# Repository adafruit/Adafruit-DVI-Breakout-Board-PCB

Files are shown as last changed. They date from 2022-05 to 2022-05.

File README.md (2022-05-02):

## Adafruit DVI Breakout Board - For HDMI Source Devices PCB

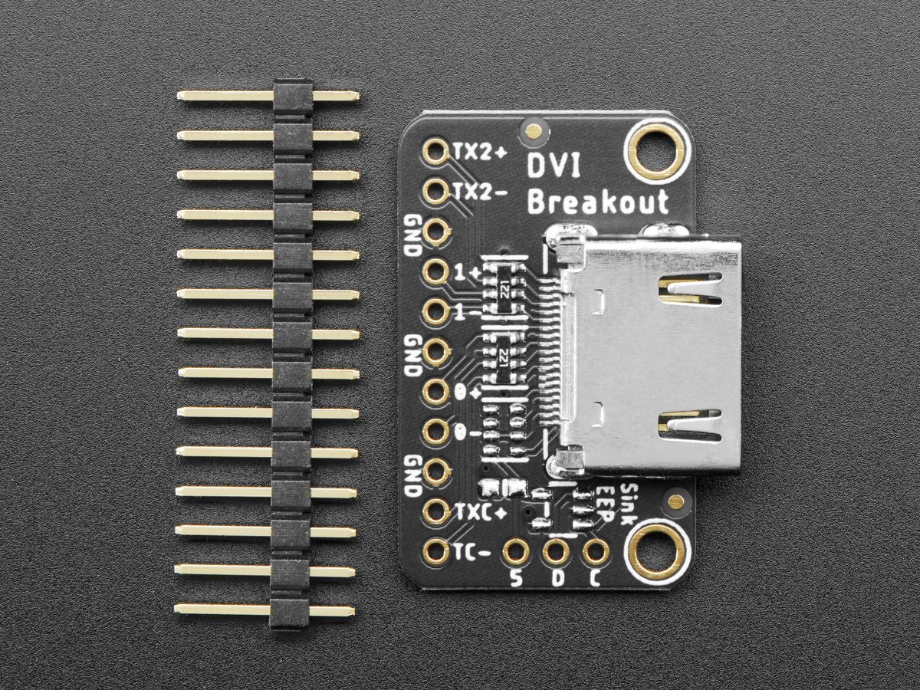
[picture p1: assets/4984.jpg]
<a href="http://www.adafruit.com/products/4984"><br/>
Click here to purchase one from the Adafruit shop</a>

PCB files for the Adafruit DVI Breakout Board - For HDMI Source Devices. 

Format is EagleCAD schematic and board layout
* https://www.adafruit.com/product/4984

### Description

We designed this little breakout board after seeing some cool demos for the Raspberry Pi Pico driving an HDMI display. By using some fun 'abuse' of overclocking and the RP2040's PIO system a low-cost microcontroller can have great looking video output. Great for making demos, or just noodling around with digital video generation.

This breakout board has no active components on it. It's just a connector you can plug an HDMI/DVI cable into, and 220 ohm series resistors. There's a spot for an I2C EEPROM and some resistors, but those are for advanced folks who may want to create a 'sink' device with an EDID. We don't place those parts on this breakout, since this is intended to be a 'source' only!

Wire it up to the bottom pins of your Pico board with the following:

GP12 to D0+

GP13 to D0-

GP14 to CK+

GP15 to CK-

GP16 to D2+

GP17 to D2-

GP18 to D1+

GP19 to D1-

And tie all the grounds together to one ground pin. Then you can download this superfun example that will give you bouncy Eben heads (from this tutorial)

### License

Adafruit invests time and resources providing this open source design, please support Adafruit and open-source hardware by purchasing products from [Adafruit](https://www.adafruit.com)!

Designed by Limor Fried/Ladyada for Adafruit Industries.

Creative Commons Attribution/Share-Alike, all text above must be included in any redistribution. 
See license.txt for additional details.

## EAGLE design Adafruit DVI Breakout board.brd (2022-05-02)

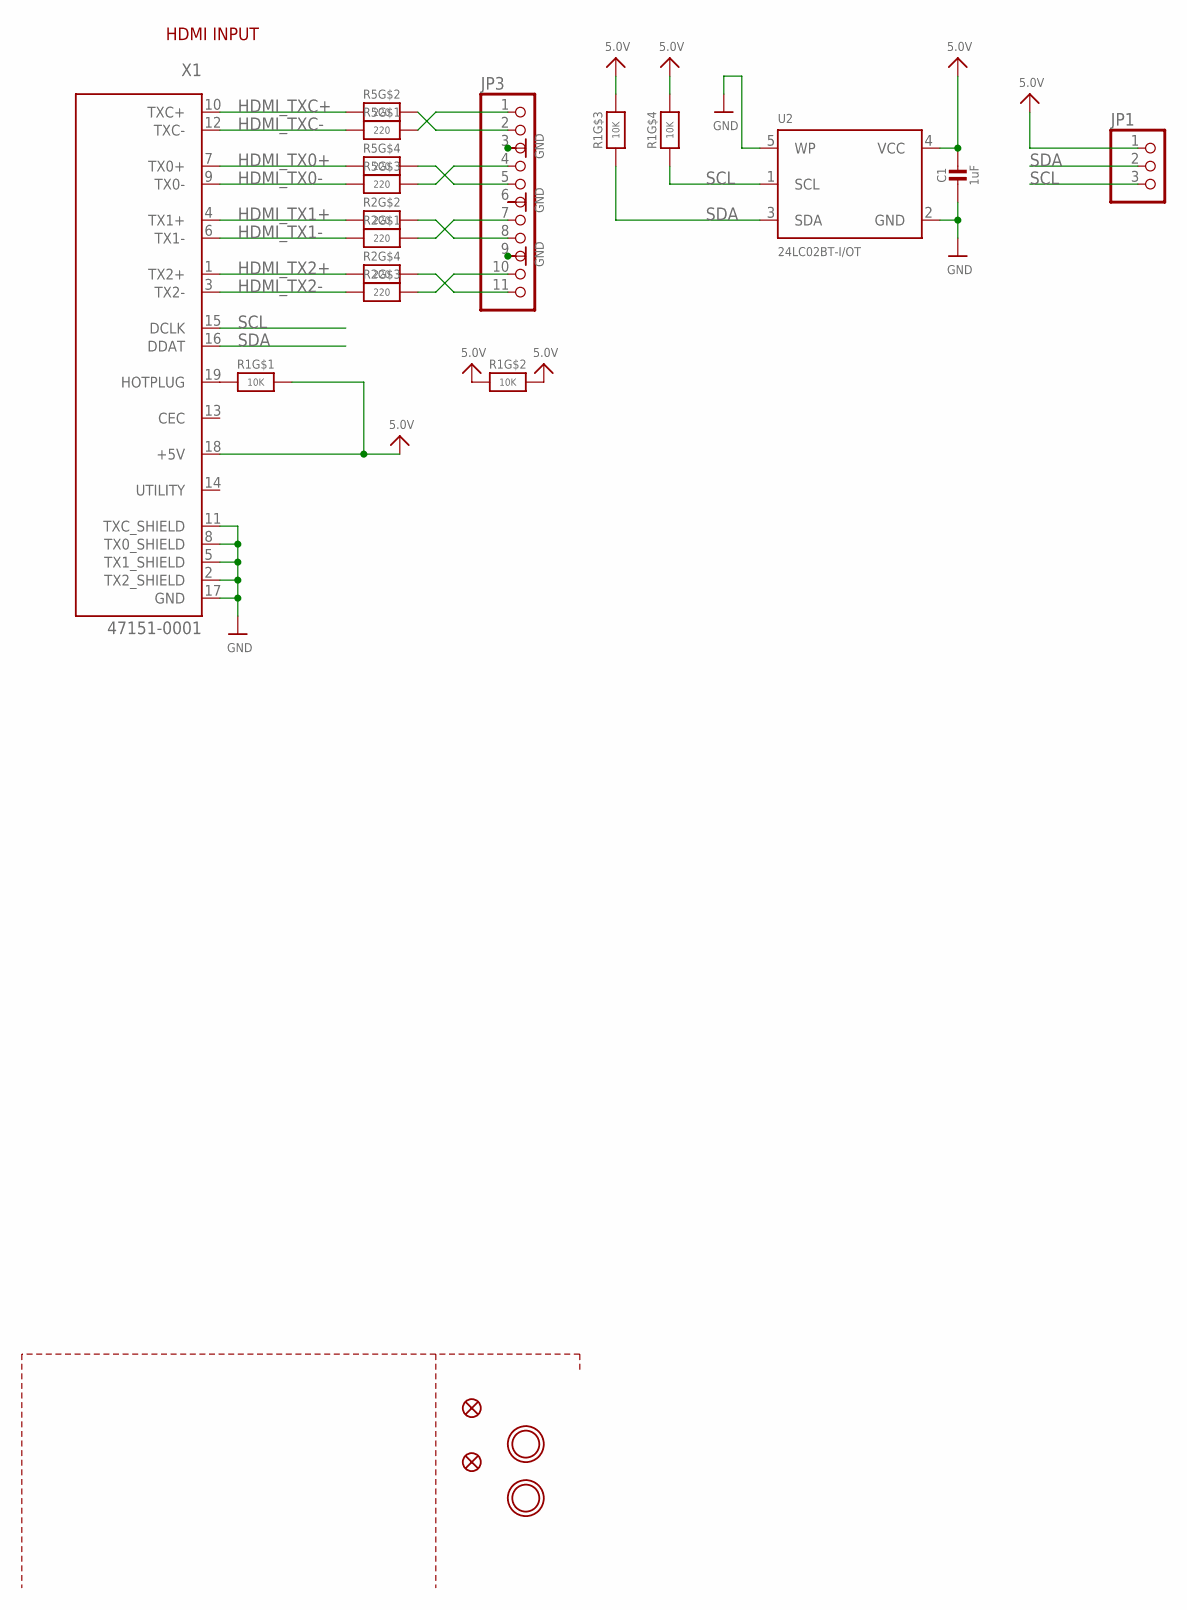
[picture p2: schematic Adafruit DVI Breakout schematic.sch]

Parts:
C1: 1uF; 0603-NO
FID1, FID2: FIDUCIAL_1MM
JP1: HEADER-1X3ROUND; 1X03_ROUND
JP3: HEADER-1X11; 1X11_ROUND
R1: 10K; RESPACK_4X0603
R2, R5: 220; RESPACK_4X0603
U2: 24LC02BT-I/OT; SOT23-5
U$32, U$33: MOUNTINGHOLE2.5; MOUNTINGHOLE_2.5_PLATED
X1: 47151-0001; HDMI_MOLEX_47151-0001

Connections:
5.0V: C1.1, JP1.1, R1.2 (1), R1.5 (2), R1.6 (2), R1.7 (2), R1.8 (2), U2.4 (VCC), X1.18 (+5V)
GND: C1.2, JP3.3, JP3.6, JP3.9, U2.2 (GND), U2.5 (WP), X1.2 (TX2_SHIELD), X1.5 (TX1_SHIELD), X1.8 (TX0_SHIELD), X1.11 (TXC_SHIELD), X1.17 (GND), X1.P$1 (GND), X1.P$2 (GND), X1.P$3 (GND), X1.P$4 (GND)
HDMI_TX0+: R5.4 (1), X1.7 (TX0+)
HDMI_TX0-: R5.3 (1), X1.9 (TX0-)
HDMI_TX1+: R2.2 (1), X1.4 (TX1+)
HDMI_TX1-: R2.1, X1.6 (TX1-)
HDMI_TX2+: R2.4 (1), X1.1 (TX2+)
HDMI_TX2-: R2.3 (1), X1.3 (TX2-)
HDMI_TXC+: R5.2 (1), X1.10 (TXC+)
HDMI_TXC-: R5.1, X1.12 (TXC-)
unnamed: R1.1, X1.19 (HOTPLUG)
SCL: JP1.3, R1.4 (1), U2.1 (SCL), X1.15 (DCLK)
SDA: JP1.2, R1.3 (1), U2.3 (SDA), X1.16 (DDAT)
TX0+: JP3.5, R5.5 (2)
TX0-: JP3.4, R5.6 (2)
TX1+: JP3.8, R2.7 (2)
TX1-: JP3.7, R2.8 (2)
TX2+: JP3.11, R2.5 (2)
TX2-: JP3.10, R2.6 (2)
TXC+: JP3.2, R5.7 (2)
TXC-: JP3.1, R5.8 (2)

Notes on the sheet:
HDMI INPUT

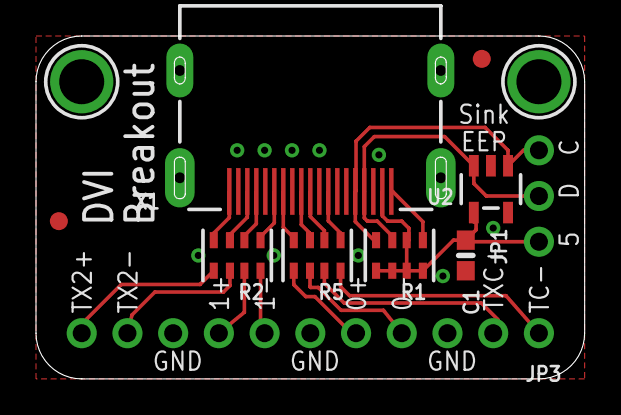
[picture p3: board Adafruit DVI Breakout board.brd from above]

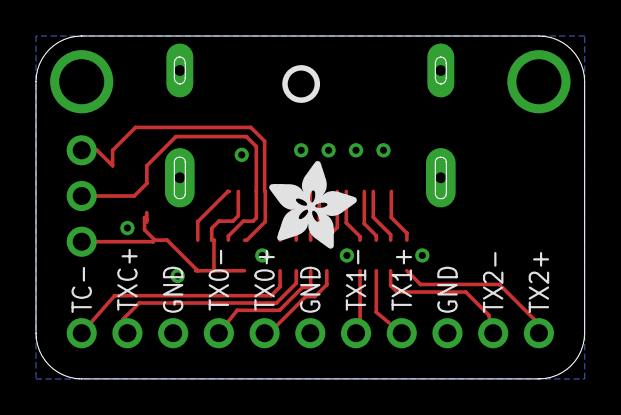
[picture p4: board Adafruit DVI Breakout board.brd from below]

Board: 2 copper layers, 30.5 x 19.1 mm, 14 parts (2 on the bottom side), 21 nets.

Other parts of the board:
U$6: ADAFRUIT_5MM
U$73: PCBFEAT-REV-040

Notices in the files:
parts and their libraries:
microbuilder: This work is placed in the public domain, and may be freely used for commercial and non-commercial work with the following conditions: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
